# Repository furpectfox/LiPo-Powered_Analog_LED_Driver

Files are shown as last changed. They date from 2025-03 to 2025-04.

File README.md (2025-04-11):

# Lipo-Powered Analog LED Driver
This circuit controls the dimming of an LED bar using only ICs and analog components&mdash;no microcontroller required. [Watch the demo here](https://youtu.be/S3qqzCgYGNY)

## [Click Me for Schematic](KiCad/schematic.pdf)

### Toggle ON/OFF
The circuit uses a push button to toggle power ON and OFF. In the OFF state, it consumes approximately 150 µA, due to current leakage through pull-up resistors.  
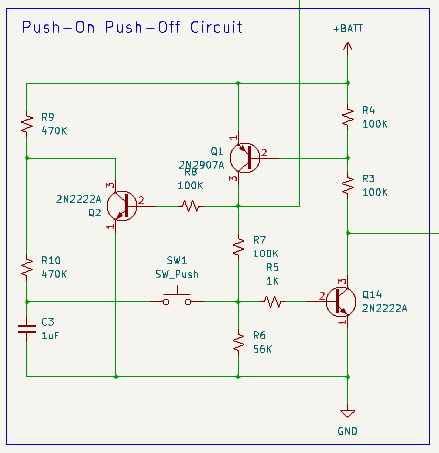
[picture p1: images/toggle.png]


### Automatic Power Down
The circuit automatically shuts down when the voltage drops to 3V. However, even in the OFF state, it still consumes 150 µA, so it does not protect the battery from discharging comepletely.  
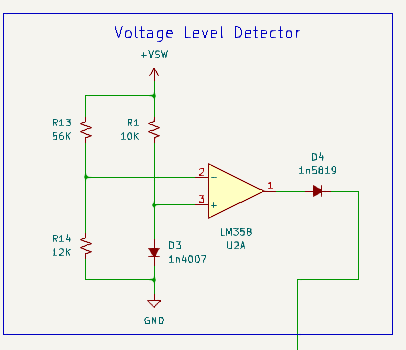
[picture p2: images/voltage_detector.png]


### Driving the LED with an N-Channel MOSFET
***Voltage Doubler***: The mosfet I'm using is a N-Channel MOSFET [IRF3205](https://www.infineon.com/dgdl/Infineon-IRF3205-DataSheet-v01_01-EN.pdf?fileId=5546d462533600a4015355def244190a). It has a Gate Threshold Voltage (Vgs) ranging from 2.0V to 4.0V. The normal operating voltage of a LiPo 18650 battery is 3.7V, and it decreases as the battery is being depleted. The solution is to have a voltage multiplier circuit to boost the voltage seen by the mosfet's gate to nearly twice the battery's voltage. This ensures the voltage driving the mosfet is always higher than the gate-source threshold voltage, even as the battery voltage decreases over time.  
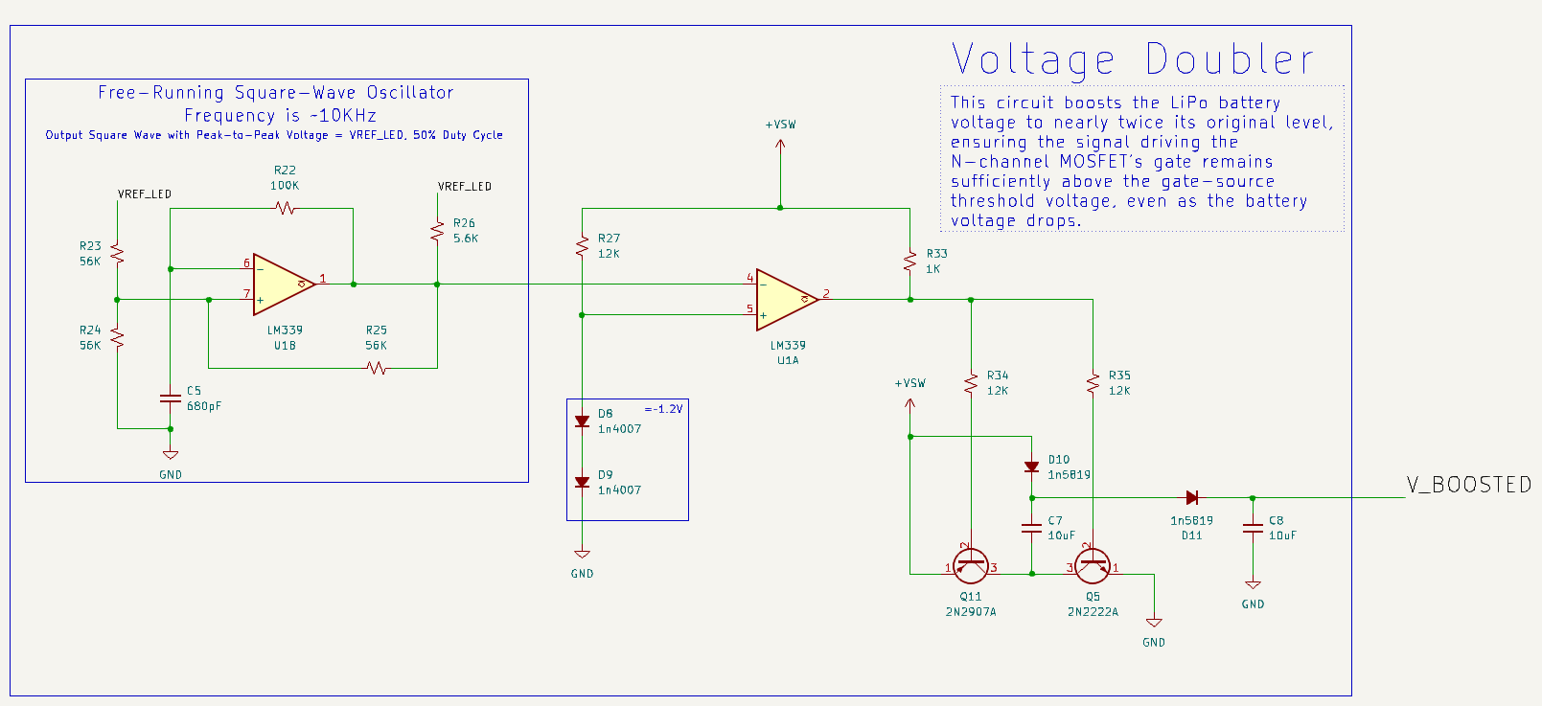
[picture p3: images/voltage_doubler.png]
  

The yellow trace shows the battery voltage (~4V). The blue trace shows the boosted voltage (~8V).  
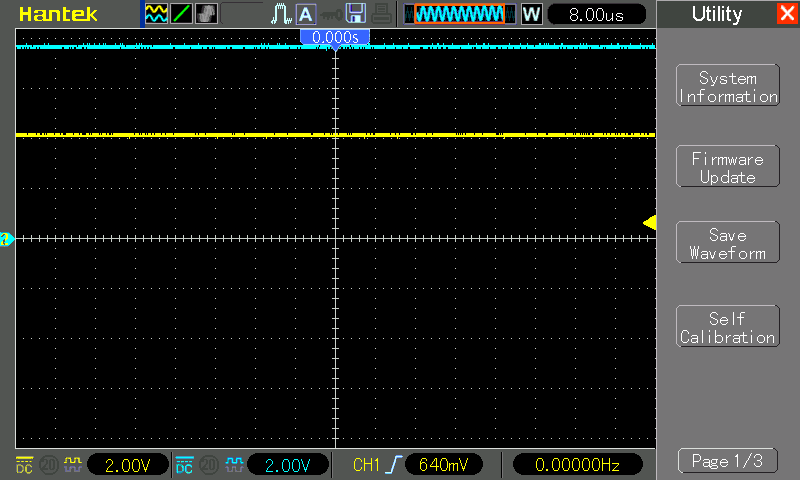
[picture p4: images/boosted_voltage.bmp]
  
  
***PWM Generator for Mosfet***:  
* A LM339 voltage comparator generates a ~800Hz square wave.
* This signal passes through a low-pass filter, converting it into a (somewhat) triangular waveform.
* A second voltage comparator compares this triangular waveform with a variable DC reference voltage (generated by a Resistor Selector Circuit).
* The result is a PWM signal with a controllable duty cycle, which drives the MOSFET gate and controls LED brightness.
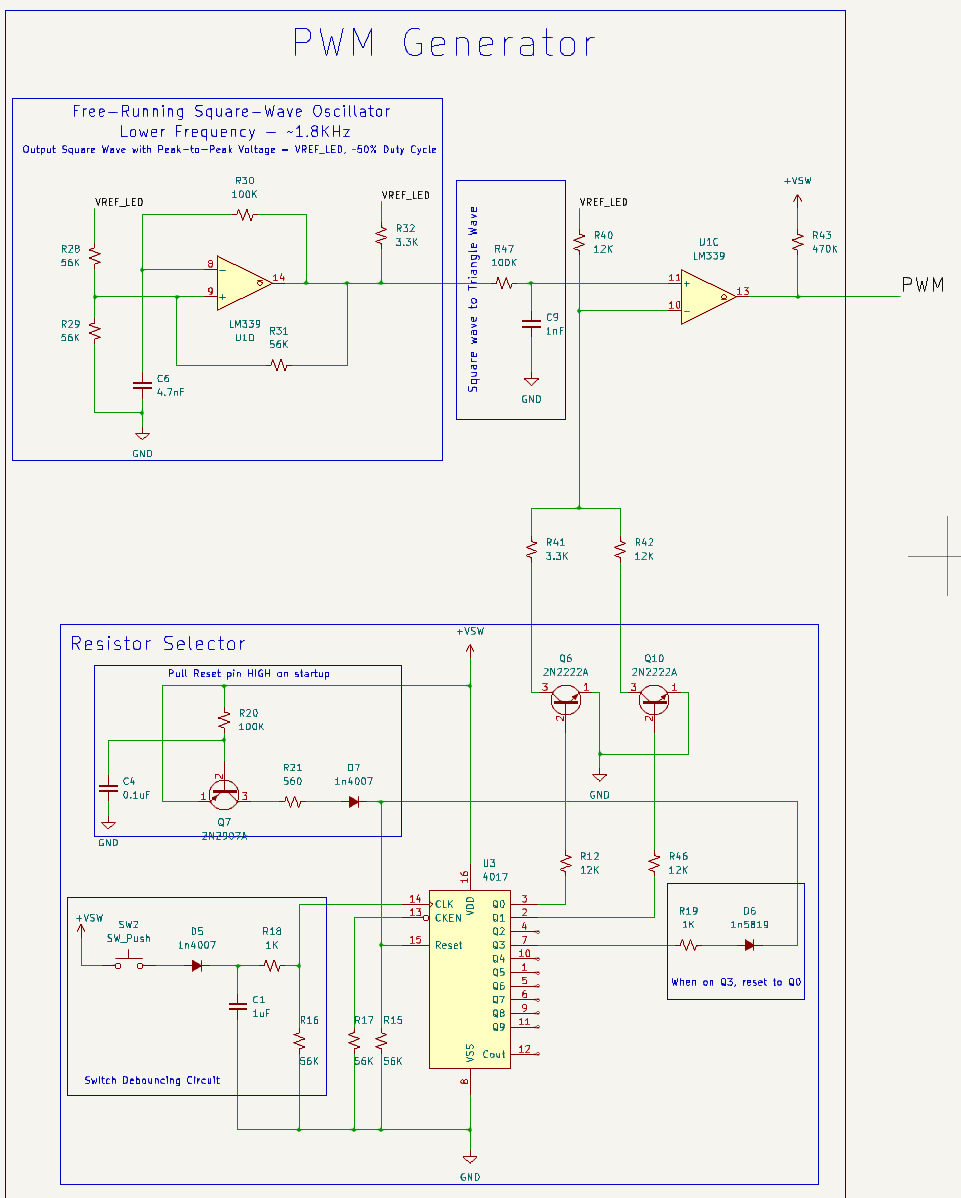
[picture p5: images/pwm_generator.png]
  

Below is an example of a 25% duty cycle PWM signal:
* Top image: Triangular wave (blue) vs. DC reference voltage (yellow). Adjusting the level of the DC reference votlage will vary the duty cycle of the output square wave.
* Bottom image: Resulting gate drive signal (blue) (~8V amplitude).  
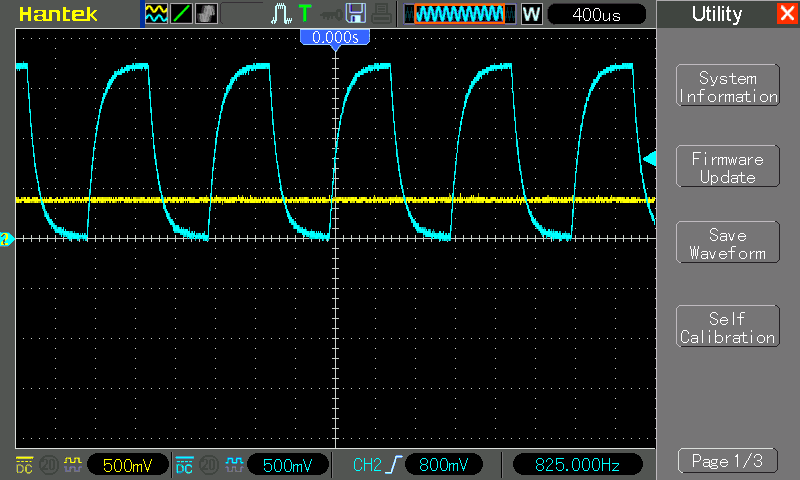
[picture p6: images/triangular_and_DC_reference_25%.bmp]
  
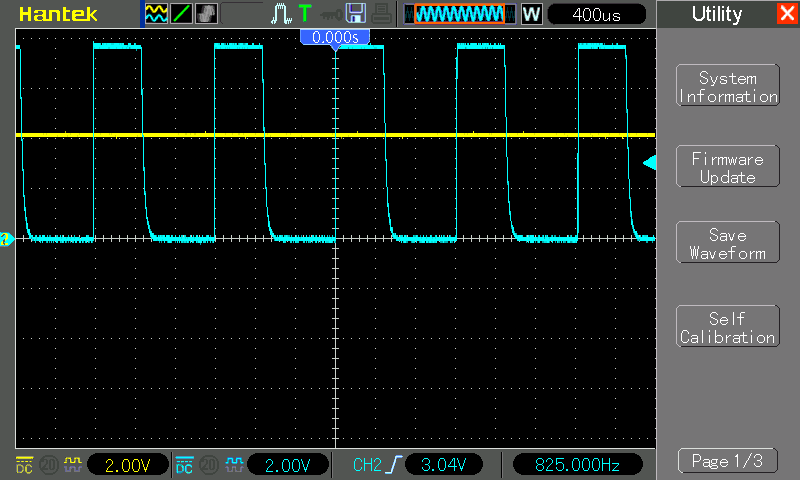
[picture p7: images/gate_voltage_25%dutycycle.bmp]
  
The circuit also allows a gradual voltage fall at the MOSFET gate, preventing high reverse voltage spikes at the drain (caused by long wiring acting as an inductor).

## Prototype
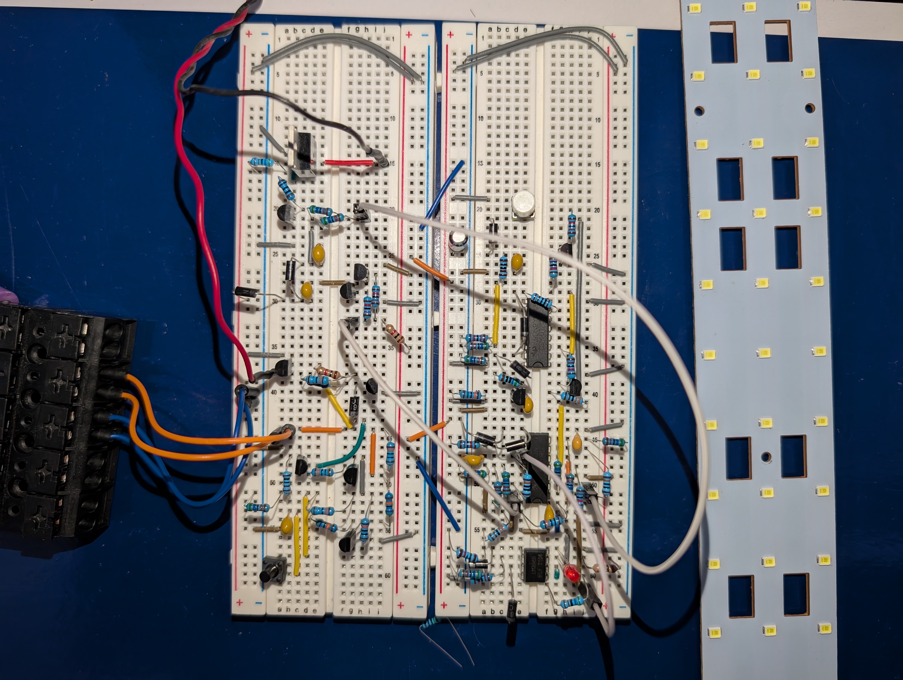
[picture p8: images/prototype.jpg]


## PCB Layout
***The PCB layout was designed for homemade single-sided PCB fabrication using [this PCB plotter attachment](https://github.com/furpectfox/PCB_Trace_Plotter)***  
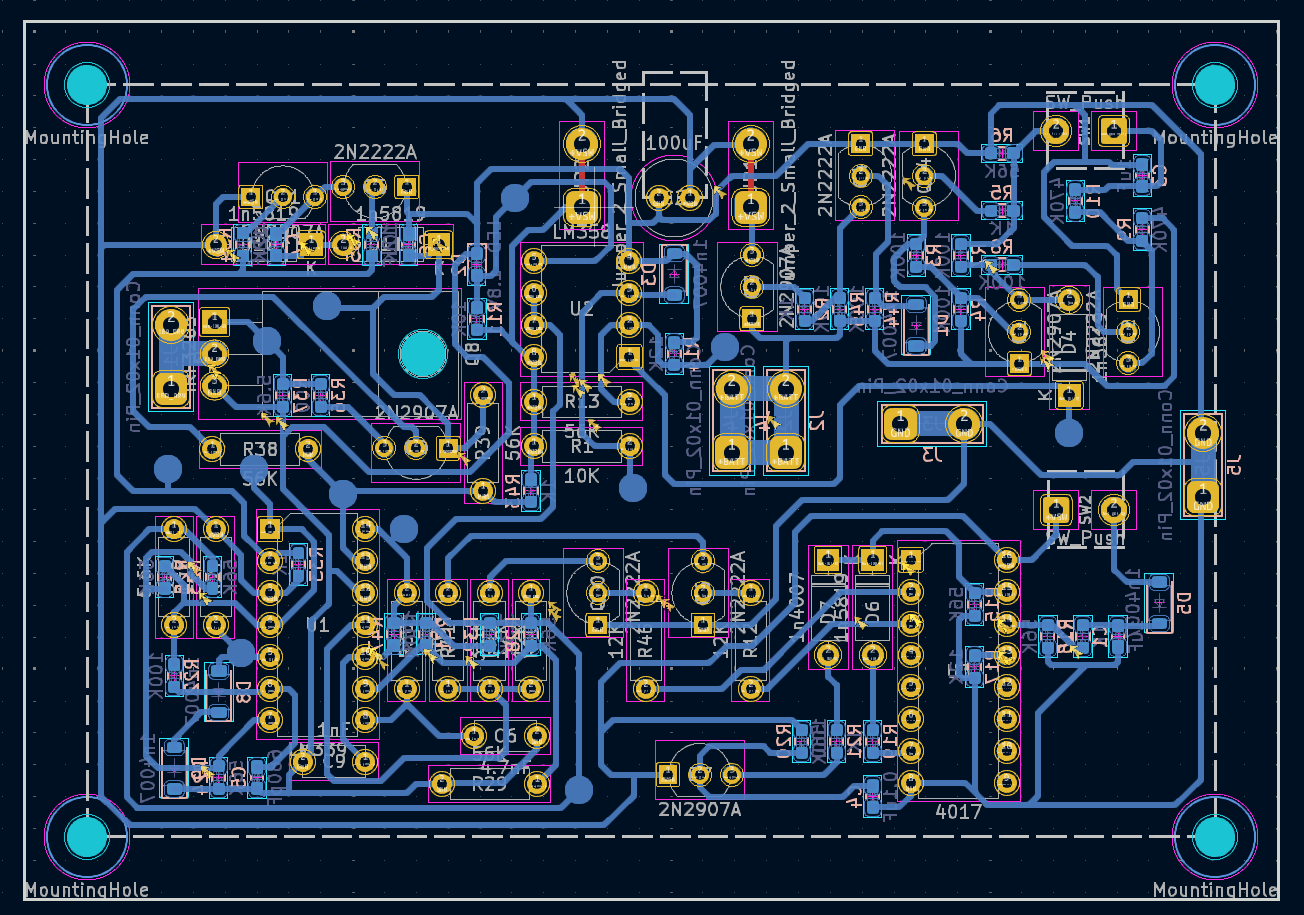
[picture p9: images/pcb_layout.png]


## Finish
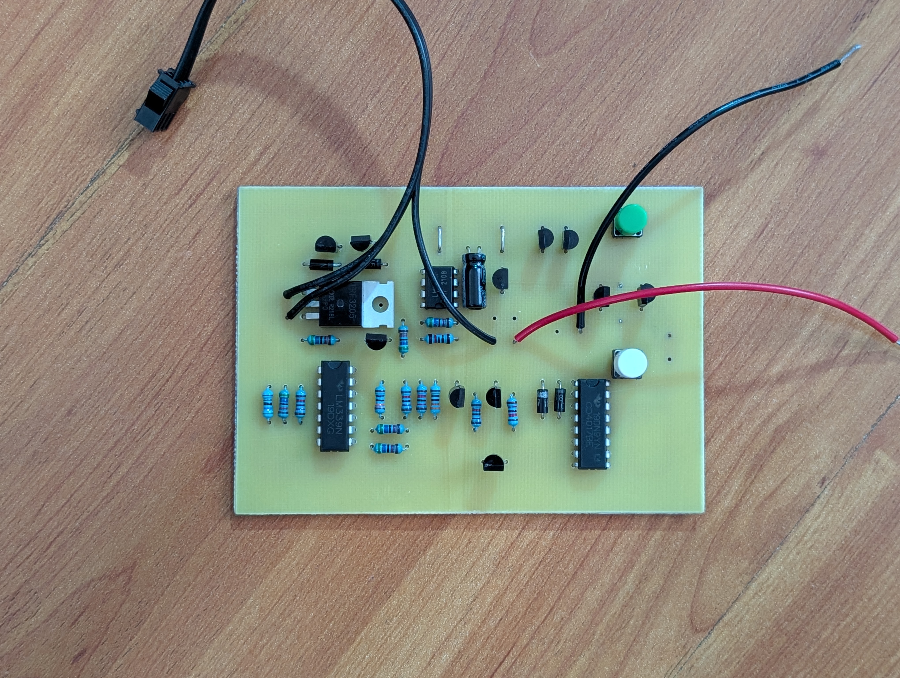
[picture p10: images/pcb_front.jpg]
  
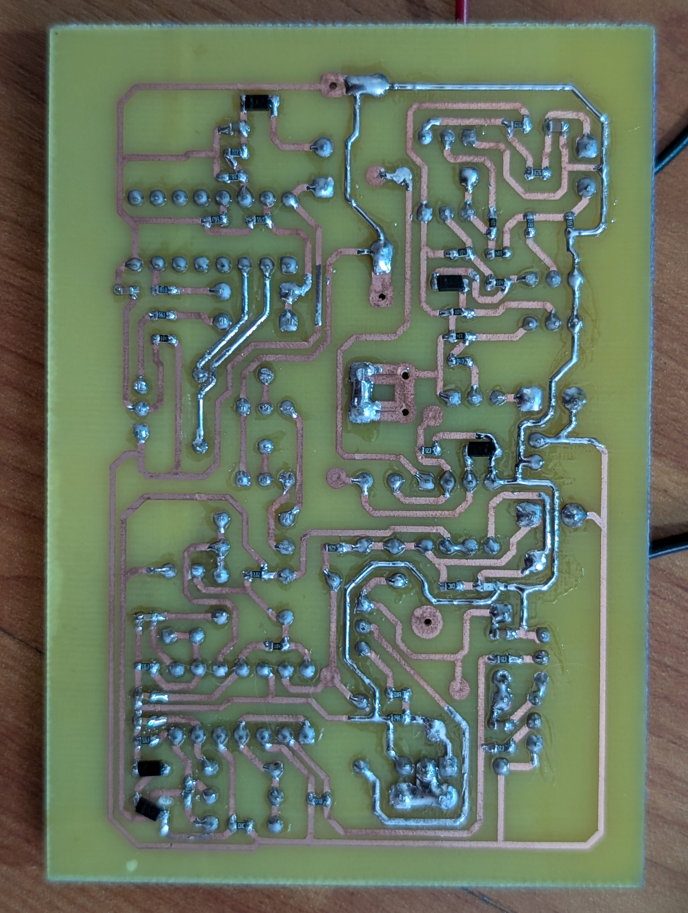
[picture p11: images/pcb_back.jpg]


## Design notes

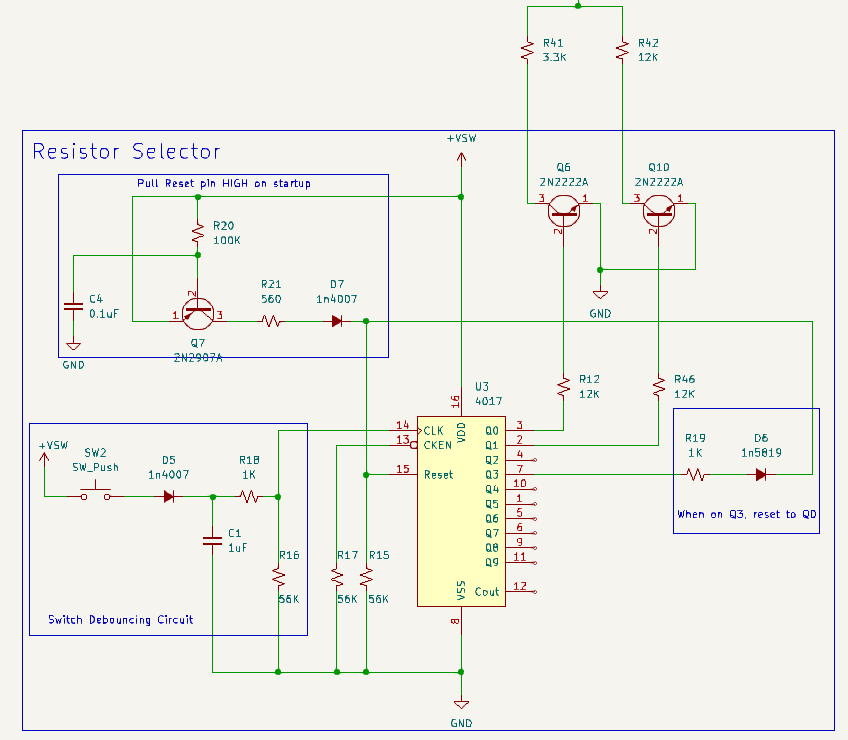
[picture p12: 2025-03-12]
images/resistor selector.png

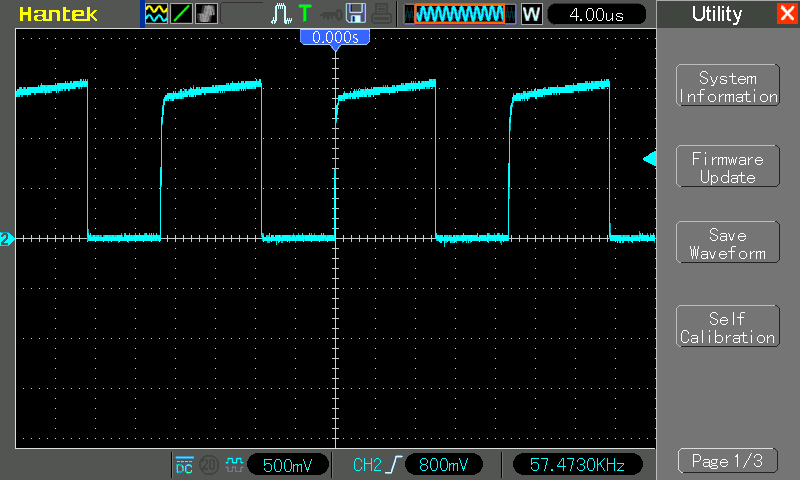
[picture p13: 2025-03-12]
images/high_frequency_square_wave.bmp

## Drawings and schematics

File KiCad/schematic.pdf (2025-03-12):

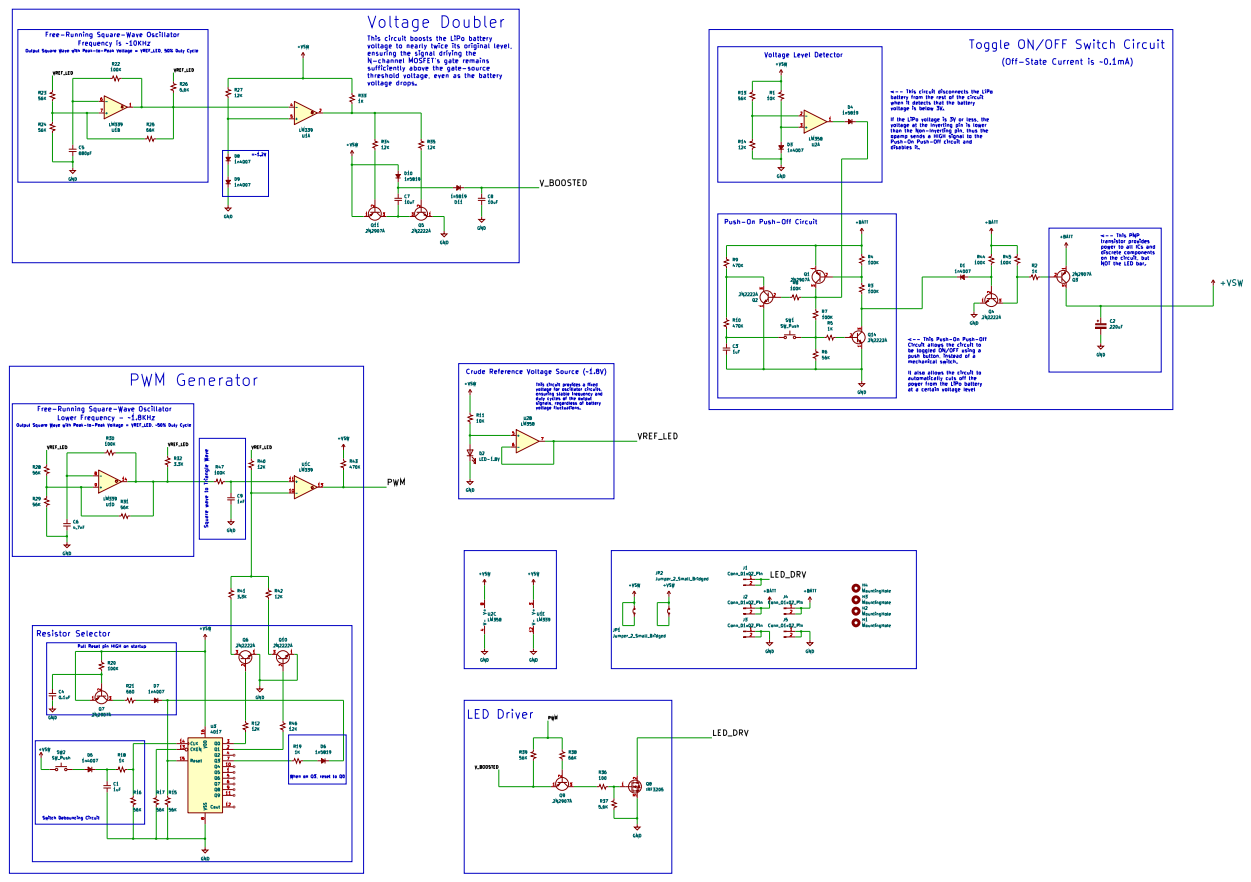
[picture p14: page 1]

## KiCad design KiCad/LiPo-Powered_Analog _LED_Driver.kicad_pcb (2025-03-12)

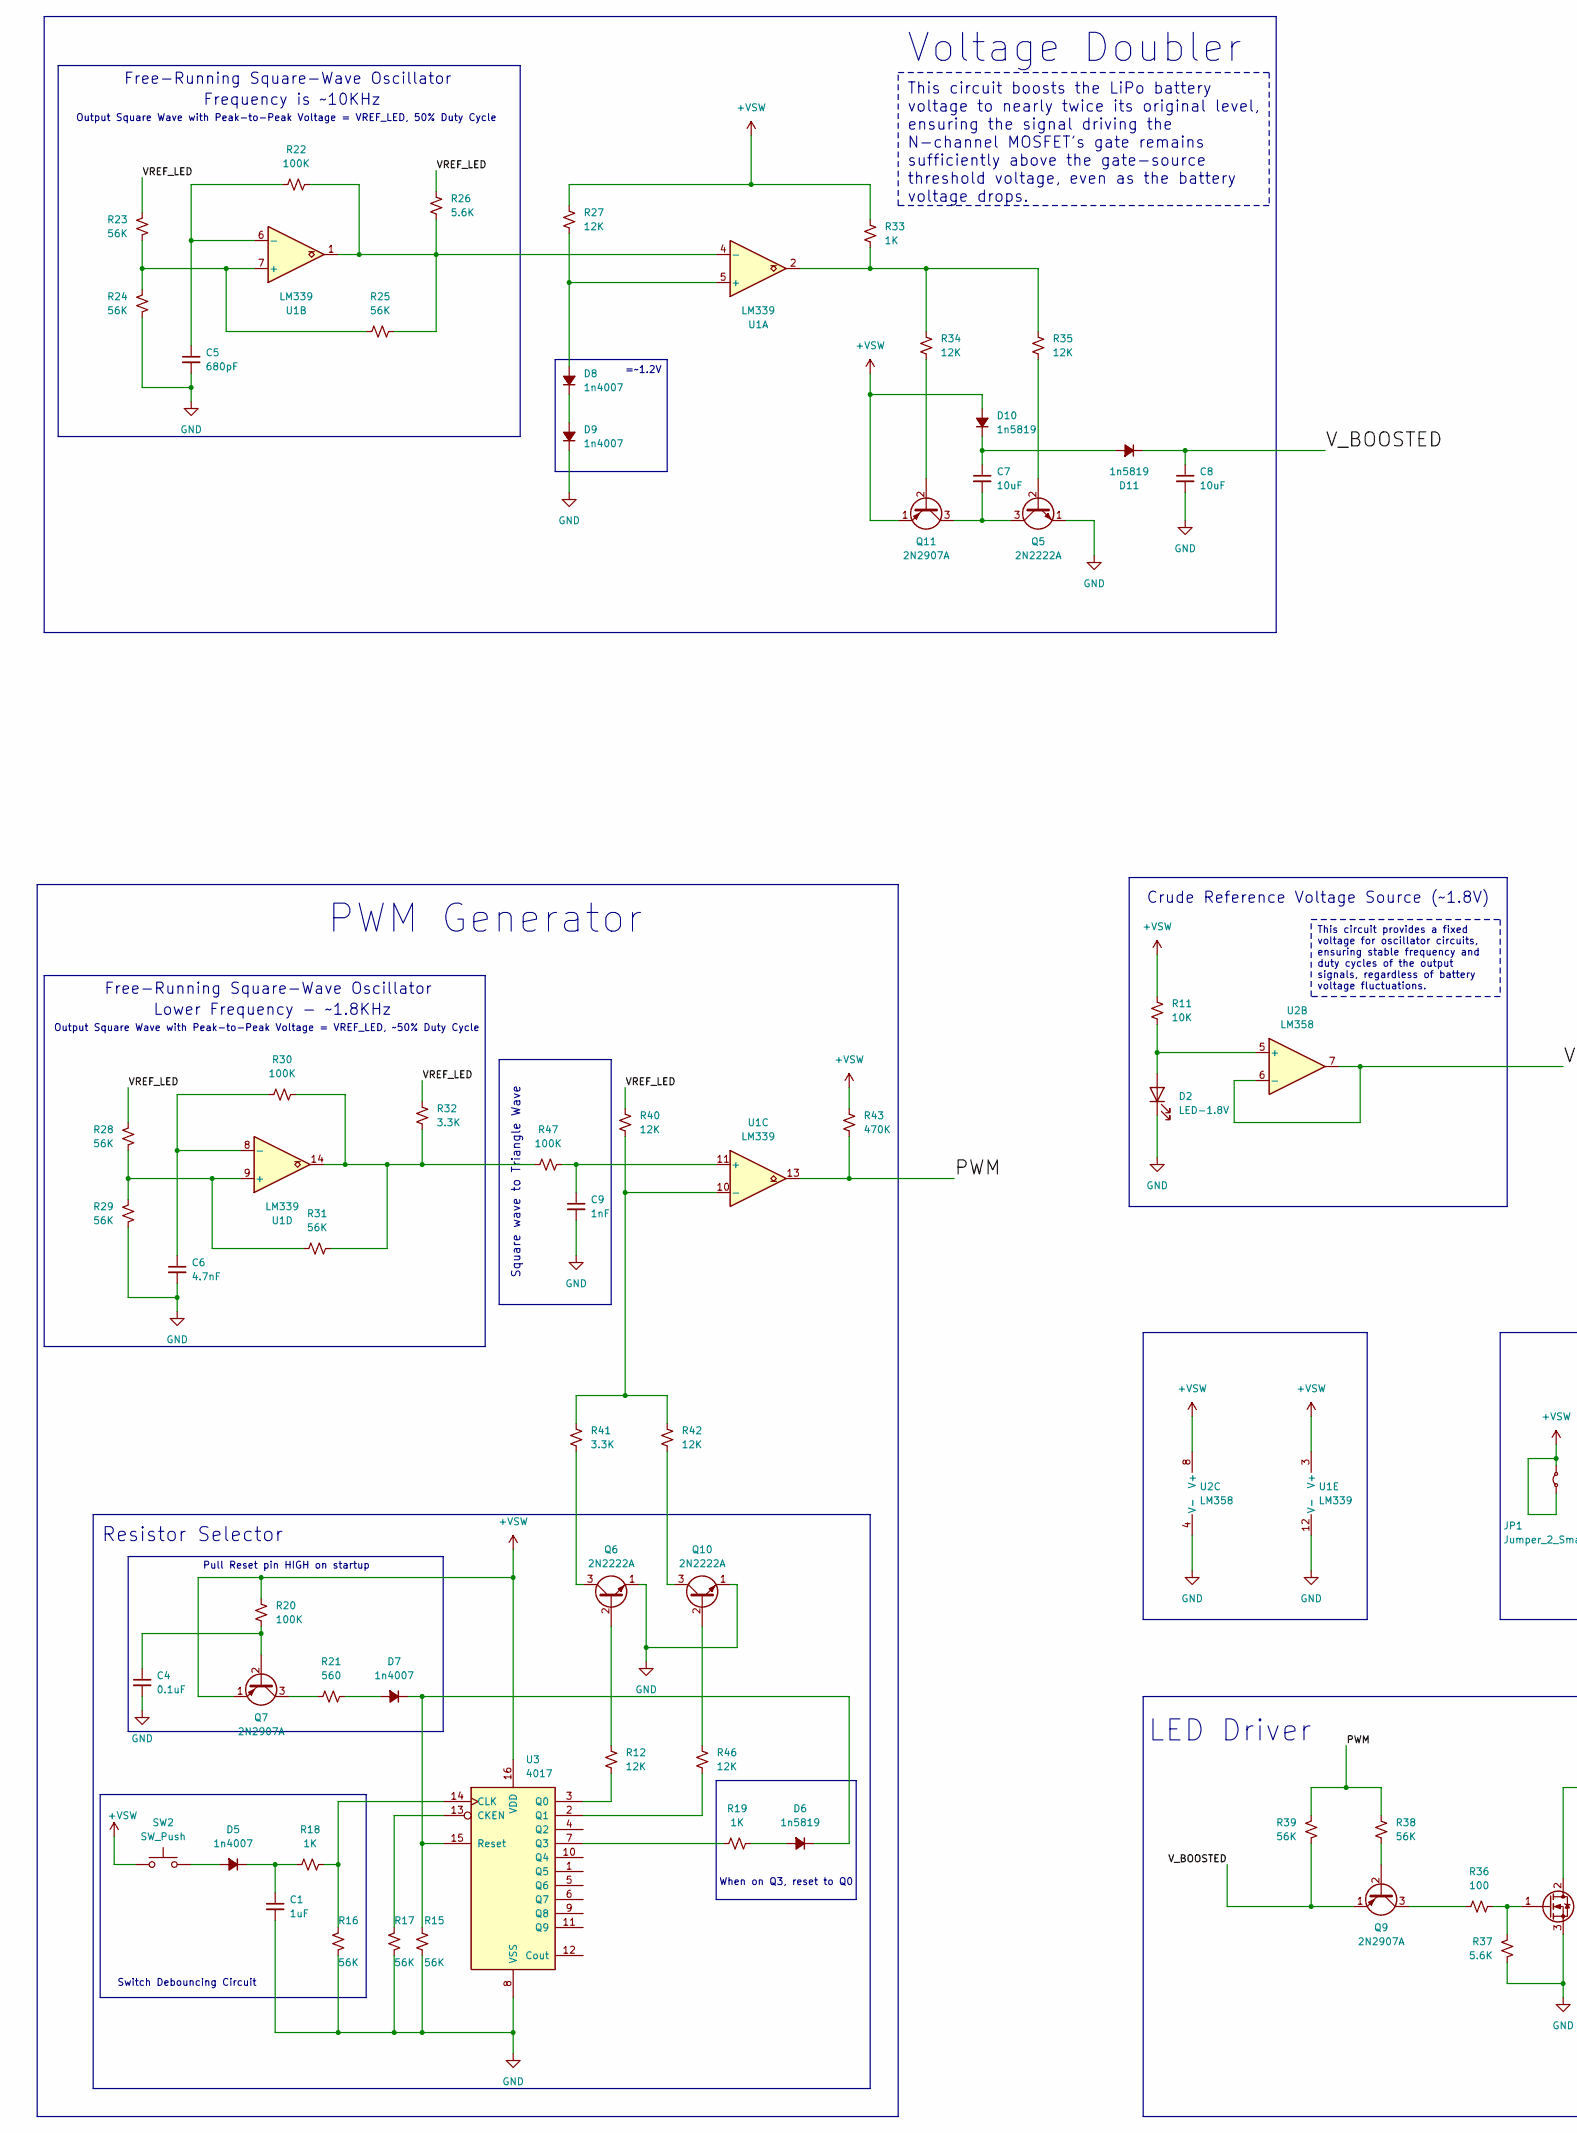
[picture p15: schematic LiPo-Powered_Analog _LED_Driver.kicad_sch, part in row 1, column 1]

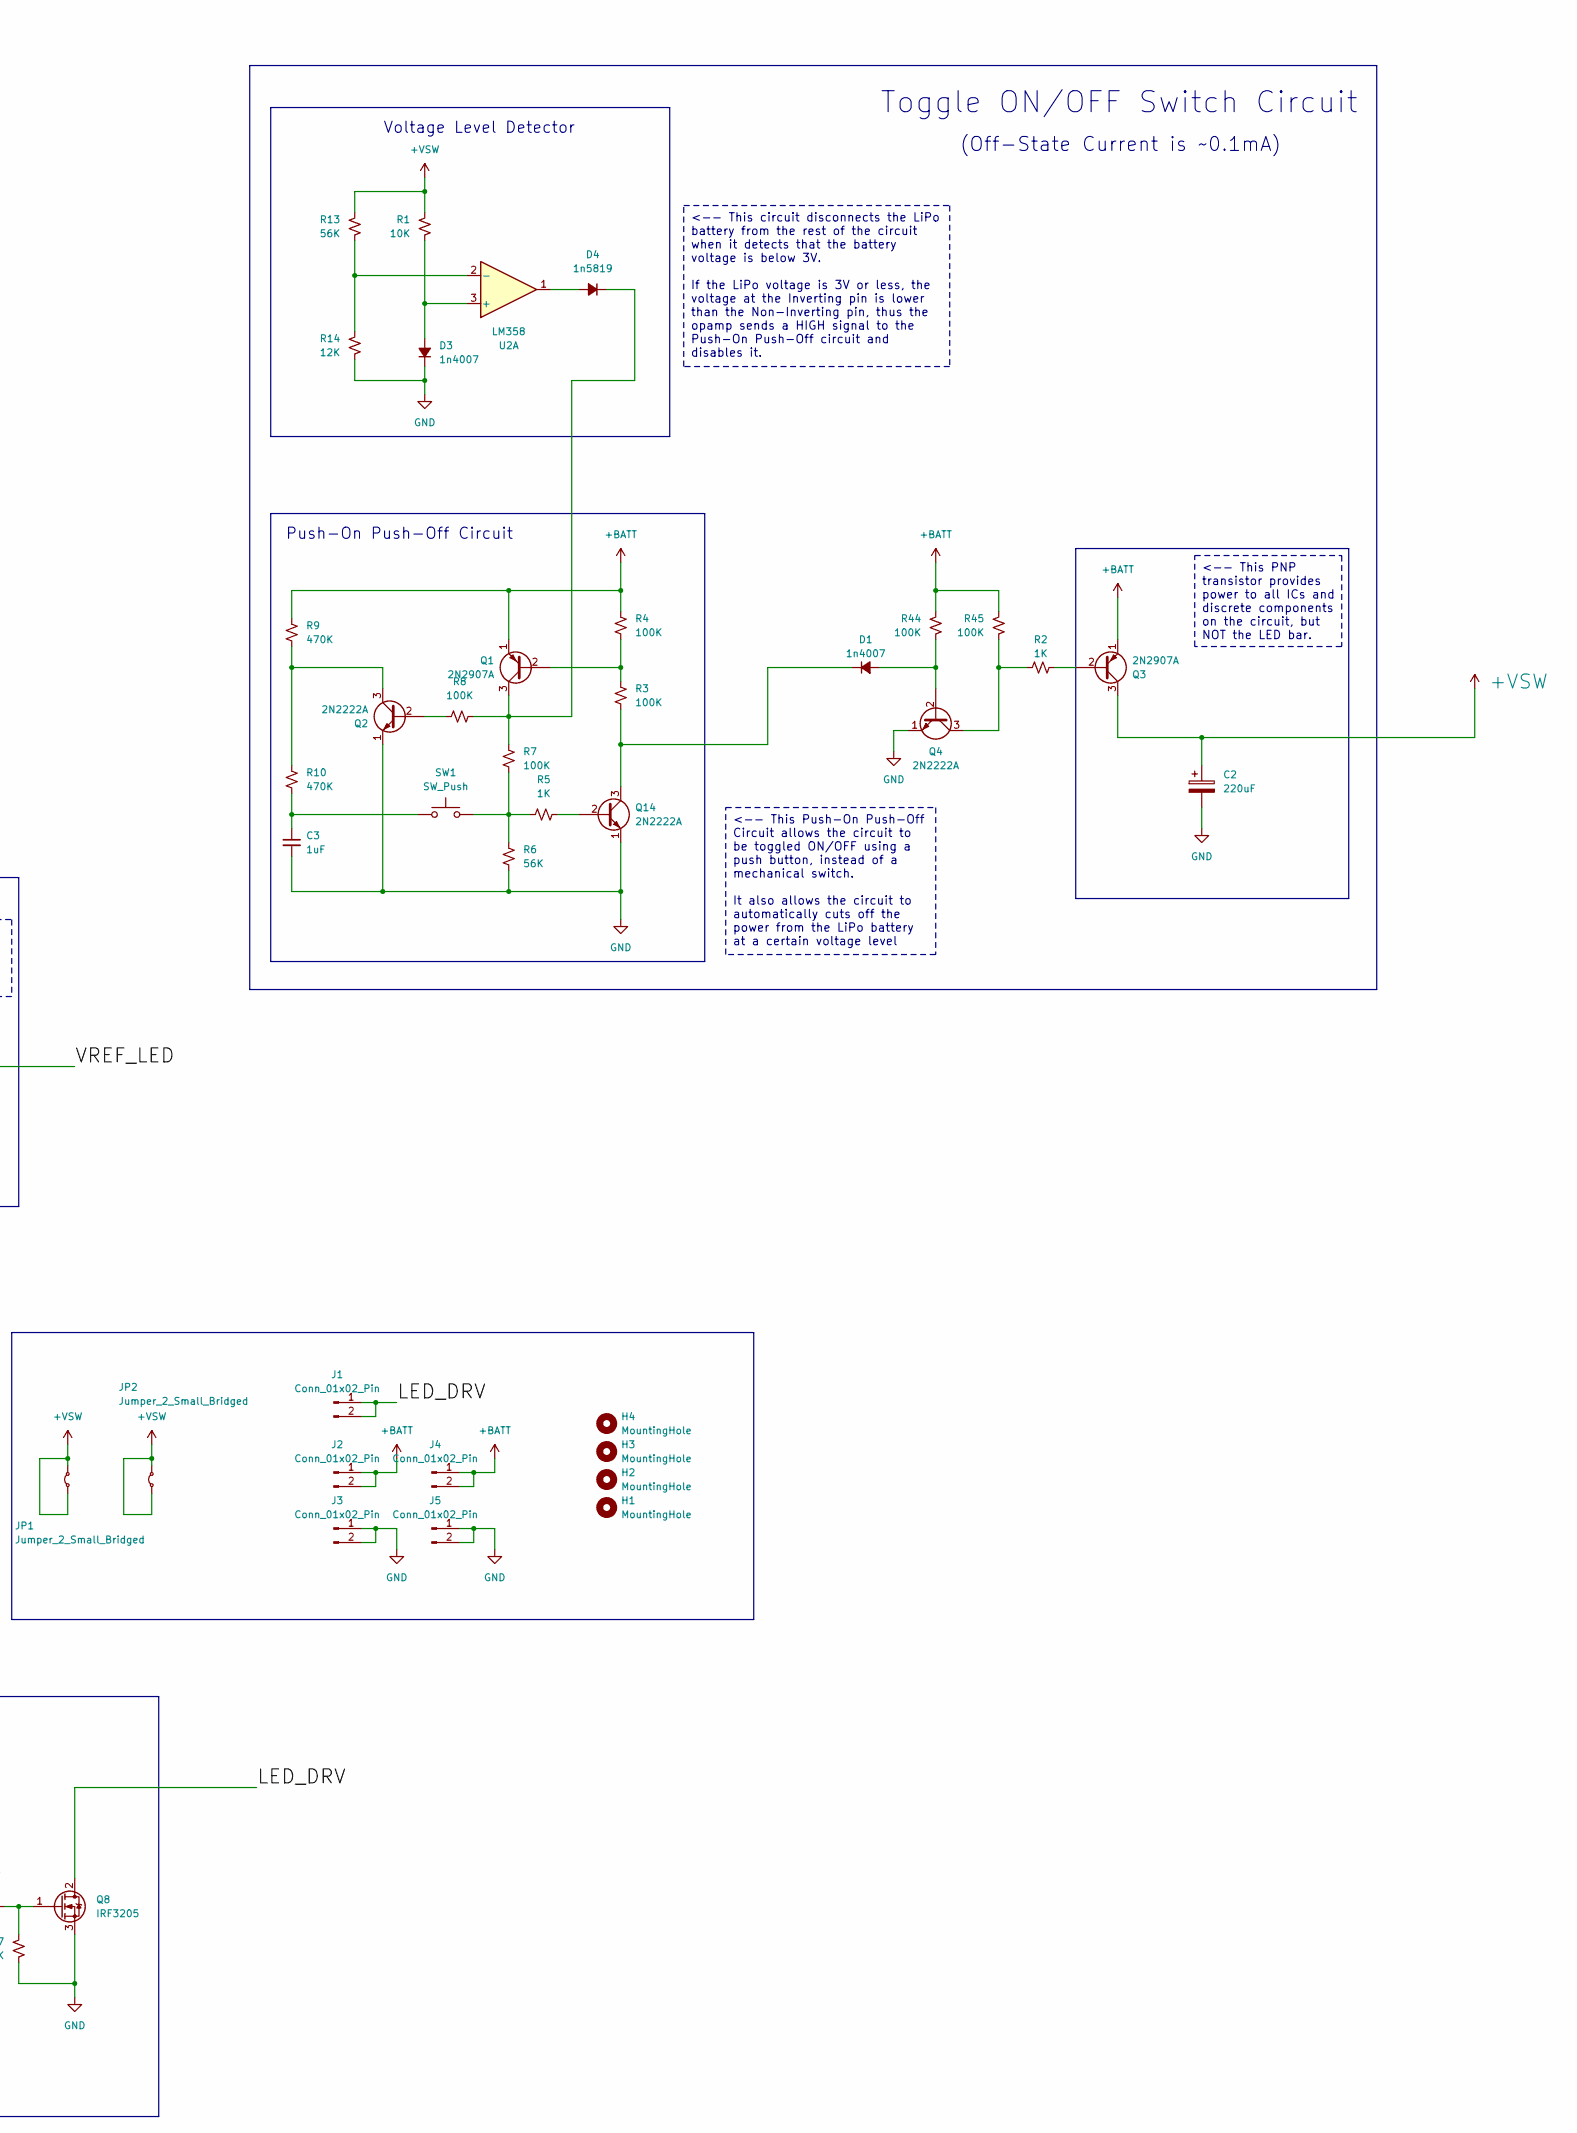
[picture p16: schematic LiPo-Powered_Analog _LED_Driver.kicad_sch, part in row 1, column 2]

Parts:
C1, C3: 1uF; C_0603_1608Metric_Pad1.08x0.95mm_HandSolder
C2: 220uF; C_Radial_D6.3mm_H11.0mm_P2.50mm
C4: 0.1uF; C_0603_1608Metric_Pad1.08x0.95mm_HandSolder
C5: 680pF; C_0603_1608Metric_Pad1.08x0.95mm_HandSolder
C6: 4.7nF; C_0603_1608Metric_Pad1.08x0.95mm_HandSolder
C7, C8: 10uF; C_0603_1608Metric_Pad1.08x0.95mm_HandSolder
C9: 1nF; C_0603_1608Metric_Pad1.08x0.95mm_HandSolder
D1, D3, D5, D8, D9: 1n4007; D_SOD-123
D2: LED-1.8V; LED_0603_1608Metric_Pad1.05x0.95mm_HandSolder
D4, D6, D10, D11: 1n5819; D_A-405_P7.62mm_Horizontal
D7: 1n4007; D_A-405_P7.62mm_Horizontal
H1, H2, H3, H4: MountingHole; MountingHole_3.2mm_M3
J1, J2, J3, J4, J5: Conn_01x02_Pin; TestPoint_2Pads_Pitch5.08mm_Drill1.3mm
JP1, JP2: Jumper_2_Small_Bridged; TestPoint_2Pads_Pitch5.08mm_Drill1.3mm
Q1, Q3, Q7, Q9, Q11: 2N2907A; TO-92_Inline_Wide
Q2, Q4, Q5, Q6, Q10, Q14: 2N2222A; TO-92_Inline_Wide
Q8: IRF3205; TO-220-3_Horizontal_TabDown
R1: 10K; R_Axial_DIN0207_L6.3mm_D2.5mm_P7.62mm_Horizontal
R2, R5, R18, R19, R33: 1K; R_0603_1608Metric_Pad0.98x0.95mm_HandSolder
R3, R4, R7, R8, R20, R44, R45, R47: 100K; R_0603_1608Metric_Pad0.98x0.95mm_HandSolder
R6, R15, R16, R17, R23, R24, R29: 56K; R_0603_1608Metric_Pad0.98x0.95mm_HandSolder
R9, R10, R43: 470K; R_0603_1608Metric_Pad0.98x0.95mm_HandSolder
R11: 10K; R_0603_1608Metric_Pad0.98x0.95mm_HandSolder
R12, R40, R42, R46: 12K; R_Axial_DIN0207_L6.3mm_D2.5mm_P7.62mm_Horizontal
R13, R25, R28, R31, R38, R39: 56K; R_Axial_DIN0207_L6.3mm_D2.5mm_P7.62mm_Horizontal
R14, R27, R34, R35: 12K; R_0603_1608Metric_Pad0.98x0.95mm_HandSolder
R21: 560; R_0603_1608Metric_Pad0.98x0.95mm_HandSolder
R22, R30: 100K; R_Axial_DIN0207_L6.3mm_D2.5mm_P7.62mm_Horizontal
R26: 5.6K; R_Axial_DIN0207_L6.3mm_D2.5mm_P7.62mm_Horizontal
R32: 3.3K; R_0603_1608Metric_Pad0.98x0.95mm_HandSolder
R36: 100; R_0603_1608Metric_Pad0.98x0.95mm_HandSolder
R37: 5.6K; R_0603_1608Metric_Pad0.98x0.95mm_HandSolder
R41: 3.3K; R_Axial_DIN0207_L6.3mm_D2.5mm_P7.62mm_Horizontal
SW1, SW2: SW_Push; SolderWire-0.5sqmm_1x02_P4.6mm_D0.9mm_OD2.1mm
U1: LM339; DIP-14_W7.62mm
U2: LM358; DIP-8_W7.62mm
U3: 4017; DIP-16_W7.62mm

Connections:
+BATT: J2.1, J2.2, J4.1, J4.2, Q1.1 (E), Q3.1 (E), R4.1, R9.1, R44.1, R45.1
+VSW: C2.1, D10.2 (A), JP1.1 (A), JP1.2 (B), JP2.1 (A), JP2.2 (B), Q3.3 (C), Q7.1 (E), Q11.1 (E), R1.1, R11.1, R13.1, R20.1, R27.1, R33.1, R43.1, SW2.1, U1.3 (V+), U2.8 (V+), U3.16 (VDD)
/LED_DRV: J1.1, J1.2, Q8.2 (D)
/PWM: R38.2, R39.1, R43.2, U1.13
/VREF_LED: R23.1, R26.1, R28.1, R32.1, R40.1, U2.6 (-), U2.7
/V_BOOSTED: C8.1, D11.1 (K), Q9.1 (E), R39.2
GND: C1.2, C2.2, C3.2, C4.2, C5.2, C6.2, C8.2, C9.2, D2.1 (K), D3.1 (K), D9.1 (K), J3.1, J3.2, J5.1, J5.2, Q2.1 (E), Q4.1 (E), Q5.1 (E), Q6.1 (E), Q8.3 (S), Q10.1 (E), Q14.1 (E), R6.2, R14.2, R15.1, R16.1, R17.1, R24.2, R29.2, R37.1, U1.12 (V-), U2.4 (V-), U3.8 (VSS)
unnamed: C3.1, R10.2, SW1.1
unnamed: D1.2 (A), Q4.2 (B), R44.2
unnamed: D1.1 (K), Q14.3 (C), R3.2
unnamed: D2.2 (A), R11.2, U2.5 (+)
unnamed: D3.2 (A), R1.2, U2.3 (+)
unnamed: D4.2 (A), U2.1
unnamed: D4.1 (K), Q1.3 (C), R7.1, R8.2
unnamed: D5.2 (A), SW2.2
unnamed: C1.1, D5.1 (K), R18.1
unnamed: D6.2 (A), R19.2
unnamed: D6.1 (K), D7.1 (K), R15.2, U3.15 (Reset)
unnamed: D7.2 (A), R21.2
unnamed: D8.2 (A), R27.2, U1.5 (+)
unnamed: D8.1 (K), D9.2 (A)
unnamed: C7.1, D10.1 (K), D11.2 (A)
unnamed: Q1.2 (B), R3.1, R4.2
unnamed: Q2.2 (B), R8.1
unnamed: Q2.3 (C), R9.2, R10.1
unnamed: Q3.2 (B), R2.2
unnamed: Q4.3 (C), R2.1, R45.2
unnamed: Q5.2 (B), R35.1
unnamed: Q6.2 (B), R12.1
unnamed: Q6.3 (C), R41.2
unnamed: C4.1, Q7.2 (B), R20.2
unnamed: Q7.3 (C), R21.1
unnamed: Q8.1 (G), R36.2, R37.2
unnamed: Q9.2 (B), R38.1
unnamed: Q9.3 (C), R36.1
unnamed: Q10.2 (B), R46.1
unnamed: Q10.3 (C), R42.2
unnamed: Q11.2 (B), R34.1
unnamed: C7.2, Q5.3 (C), Q11.3 (C)
unnamed: Q14.2 (B), R5.2
unnamed: R5.1, R6.1, R7.2, SW1.2
unnamed: R30.2, R31.2, R32.2, R47.1, U1.14
unnamed: R33.2, R34.2, R35.2, U1.2
unnamed: R22.2, R25.2, R26.2, U1.1, U1.4 (-)
unnamed: R23.2, R24.1, R25.1, U1.7 (+)
unnamed: C5.1, R22.1, U1.6 (-)
unnamed: C9.1, R47.2, U1.11 (+)
unnamed: R40.2, R41.1, R42.1, U1.10 (-)
unnamed: R28.2, R29.1, R31.1, U1.9 (+)
unnamed: C6.1, R30.1, U1.8 (-)
unnamed: R13.2, R14.1, U2.2 (-)
unnamed: R17.2, U3.13 (CKEN)
unnamed: R16.2, R18.2, U3.14 (CLK)
unnamed: R12.2, U3.3 (Q0)
unnamed: R46.2, U3.2 (Q1)
unnamed: R19.1, U3.7 (Q3)

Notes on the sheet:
<-- This circuit disconnects the LiPo battery from the rest of the circuit when it detects that the battery voltage is below 3V. If the LiPo voltage is 3V or less, the voltage at the Inverting pin is lower than the Non-Inverting pin, thus the opamp sends a HIGH signal to the Push-On Push-Off circui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
This circuit boosts the LiPo battery voltage to nearly twice its original level, ensuring the signal driving the N-channel MOSFET's gate remains sufficiently above the gate-source threshold voltage, even as the battery voltage drops.
<-- This Push-On Push-Off Circuit allows the circuit to be toggled ON/OFF using a push button, instead of a mechanical switch. It also allows the circuit to automatically cuts off the power from the LiPo battery at a certain voltage level
<-- This PNP transistor provides power to all ICs and discrete components on the circuit, but NOT the LED bar.
This circuit provides a fixed voltage for oscillator circuits, ensuring stable frequency and duty cycles of the output signals, regardless of battery voltage fluctuations.
LED Driver
Frequency is ~10KHz
Crude Reference Voltage Source (~1.8V)
Voltage Level Detector
Free-Running Square-Wave Oscillator
Push-On Push-Off Circuit
PWM Generator
Output Square Wave with Peak-to-Peak Voltage = VREF_LED, 50% Duty Cycle
Resistor Selector
Lower Frequency - ~1.8KHz
Toggle ON/OFF Switch Circuit
Square wave to Triangle Wave
When on Q3, reset to Q0
Output Square Wave with Peak-to-Peak Voltage = VREF_LED, ~50% Duty Cycle
(Off-State Current is ~0.1mA)
Voltage Doubler
=~1.2V
Pull Reset pin HIGH on startup
Switch Debouncing Circuit

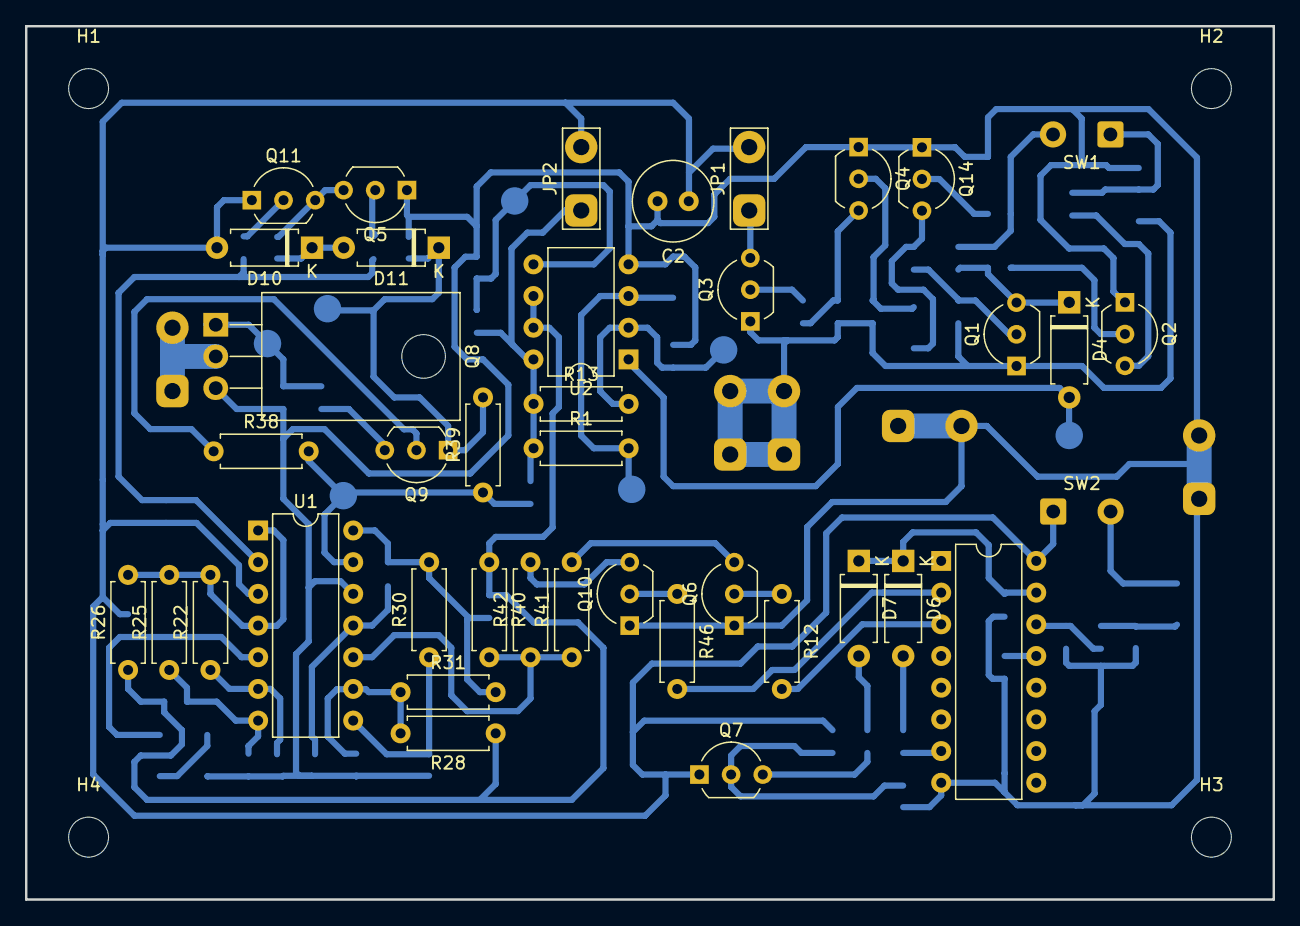
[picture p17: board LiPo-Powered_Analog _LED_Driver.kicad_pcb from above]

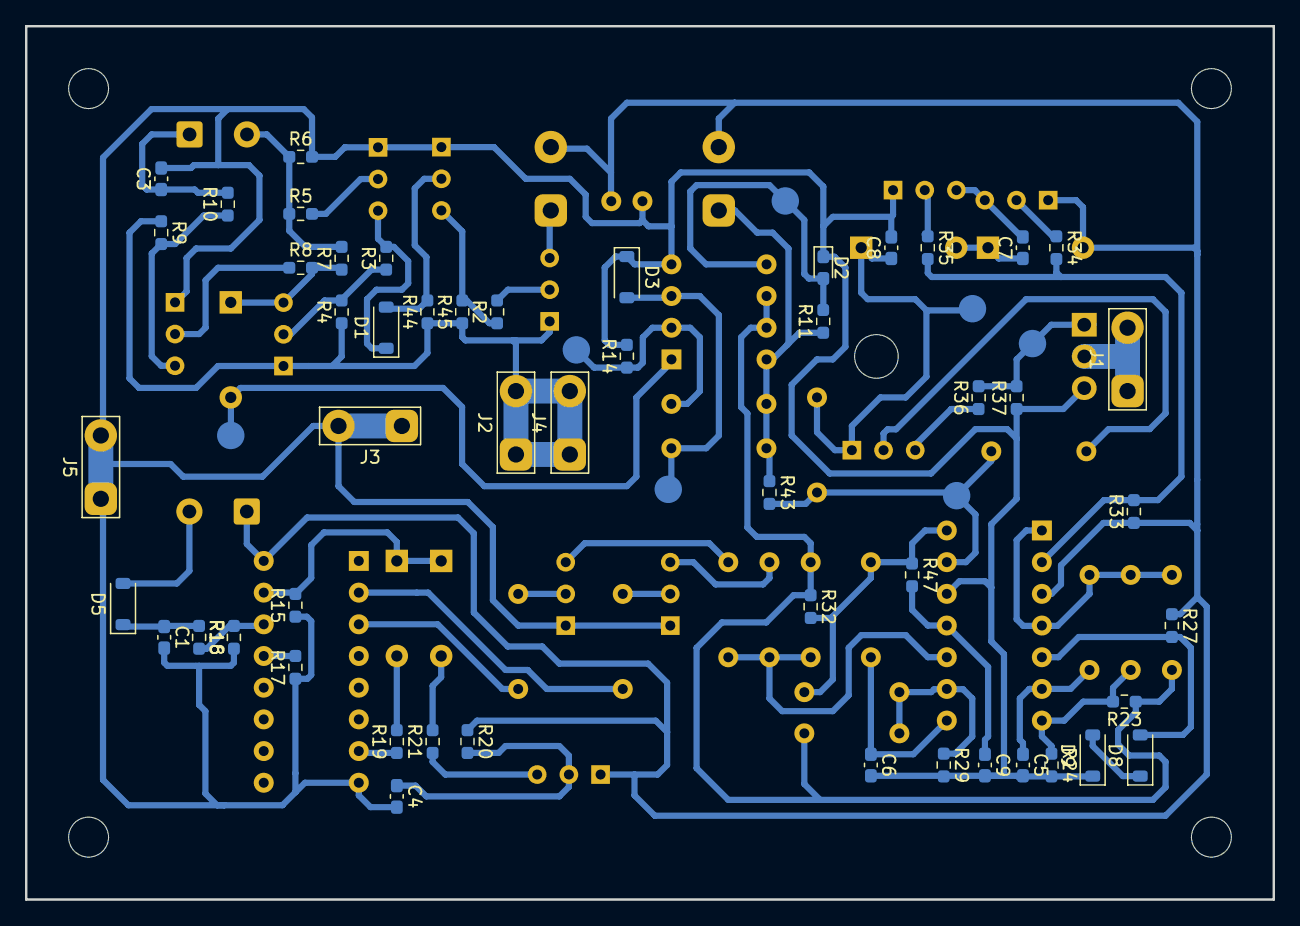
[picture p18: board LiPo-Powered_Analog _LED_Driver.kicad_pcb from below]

Board: 2 copper layers, 100.0 x 70.0 mm, 95 parts (51 on the bottom side), 56 nets.

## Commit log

2025-03-03 add schematic
2025-03-09 update schematic. Add PCB layout
    [LiPo-Powered_Analog _LED_Driver.kicad_pcb, LiPo-Powered_Analog _LED_Driver.kicad_sch]
2025-03-09 Add file to KiCad folder
2025-03-12 Update schematic and PCB layout. Add images
    [LiPo-Powered_Analog _LED_Driver.kicad_pcb, LiPo-Powered_Analog _LED_Driver.kicad_sch]
